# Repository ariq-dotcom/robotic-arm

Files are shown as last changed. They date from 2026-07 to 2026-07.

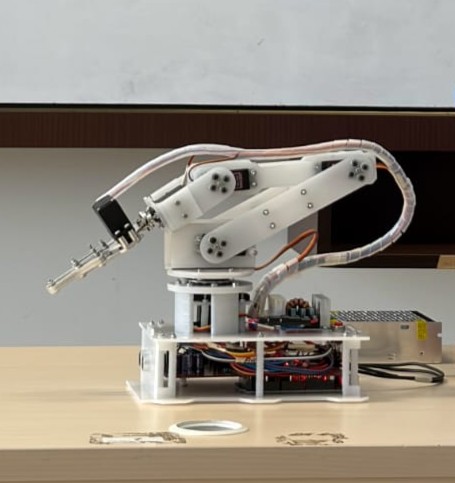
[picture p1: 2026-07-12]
Dokumentasi/4.jpeg

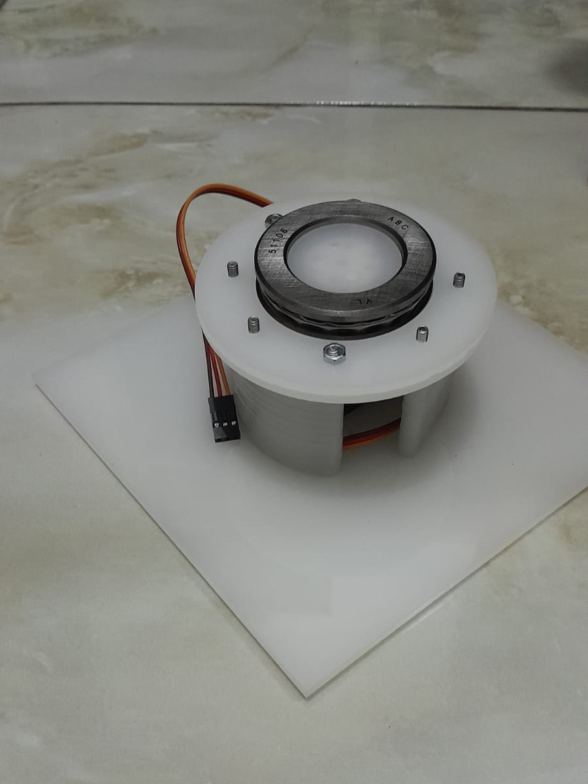
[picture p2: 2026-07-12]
Dokumentasi/1.jpeg

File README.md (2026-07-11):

Repository ini berisi file-file pengembangan robot arm 5 DOF berbasis Arduino Mega, meliputi desain elektrikal (PCB), program kendali

Pada folder ARM KENDALI, setiap angka pada nama file .ino menunjukkan urutan perkembangan dan pembaruan program sejak tahap awal pengembangan ketika isi program masih berupa struktur dasar dan belum sepenuhnya siap digunakan. File dengan angka terbesar merupakan program versi terbaru.

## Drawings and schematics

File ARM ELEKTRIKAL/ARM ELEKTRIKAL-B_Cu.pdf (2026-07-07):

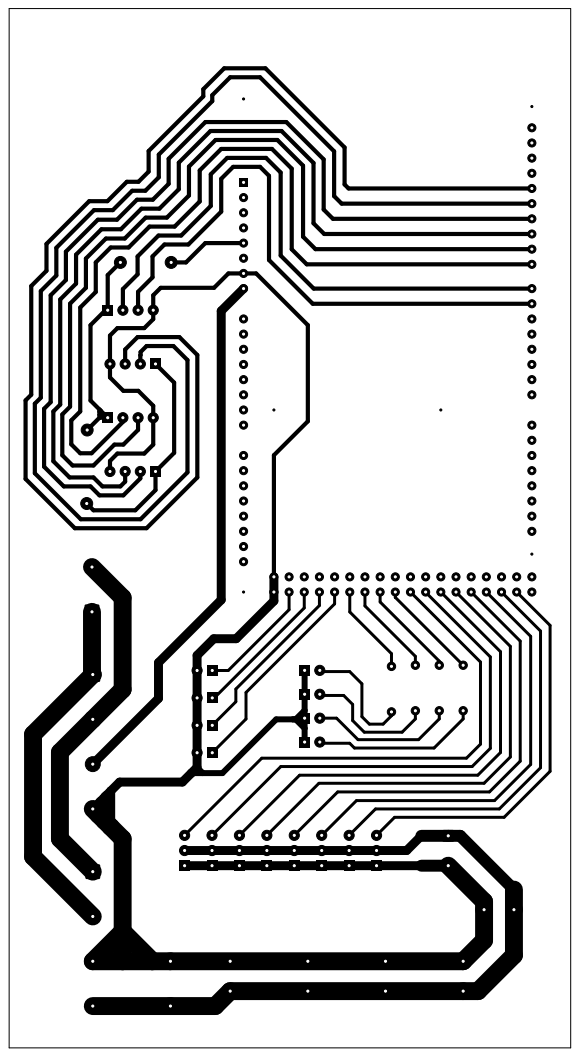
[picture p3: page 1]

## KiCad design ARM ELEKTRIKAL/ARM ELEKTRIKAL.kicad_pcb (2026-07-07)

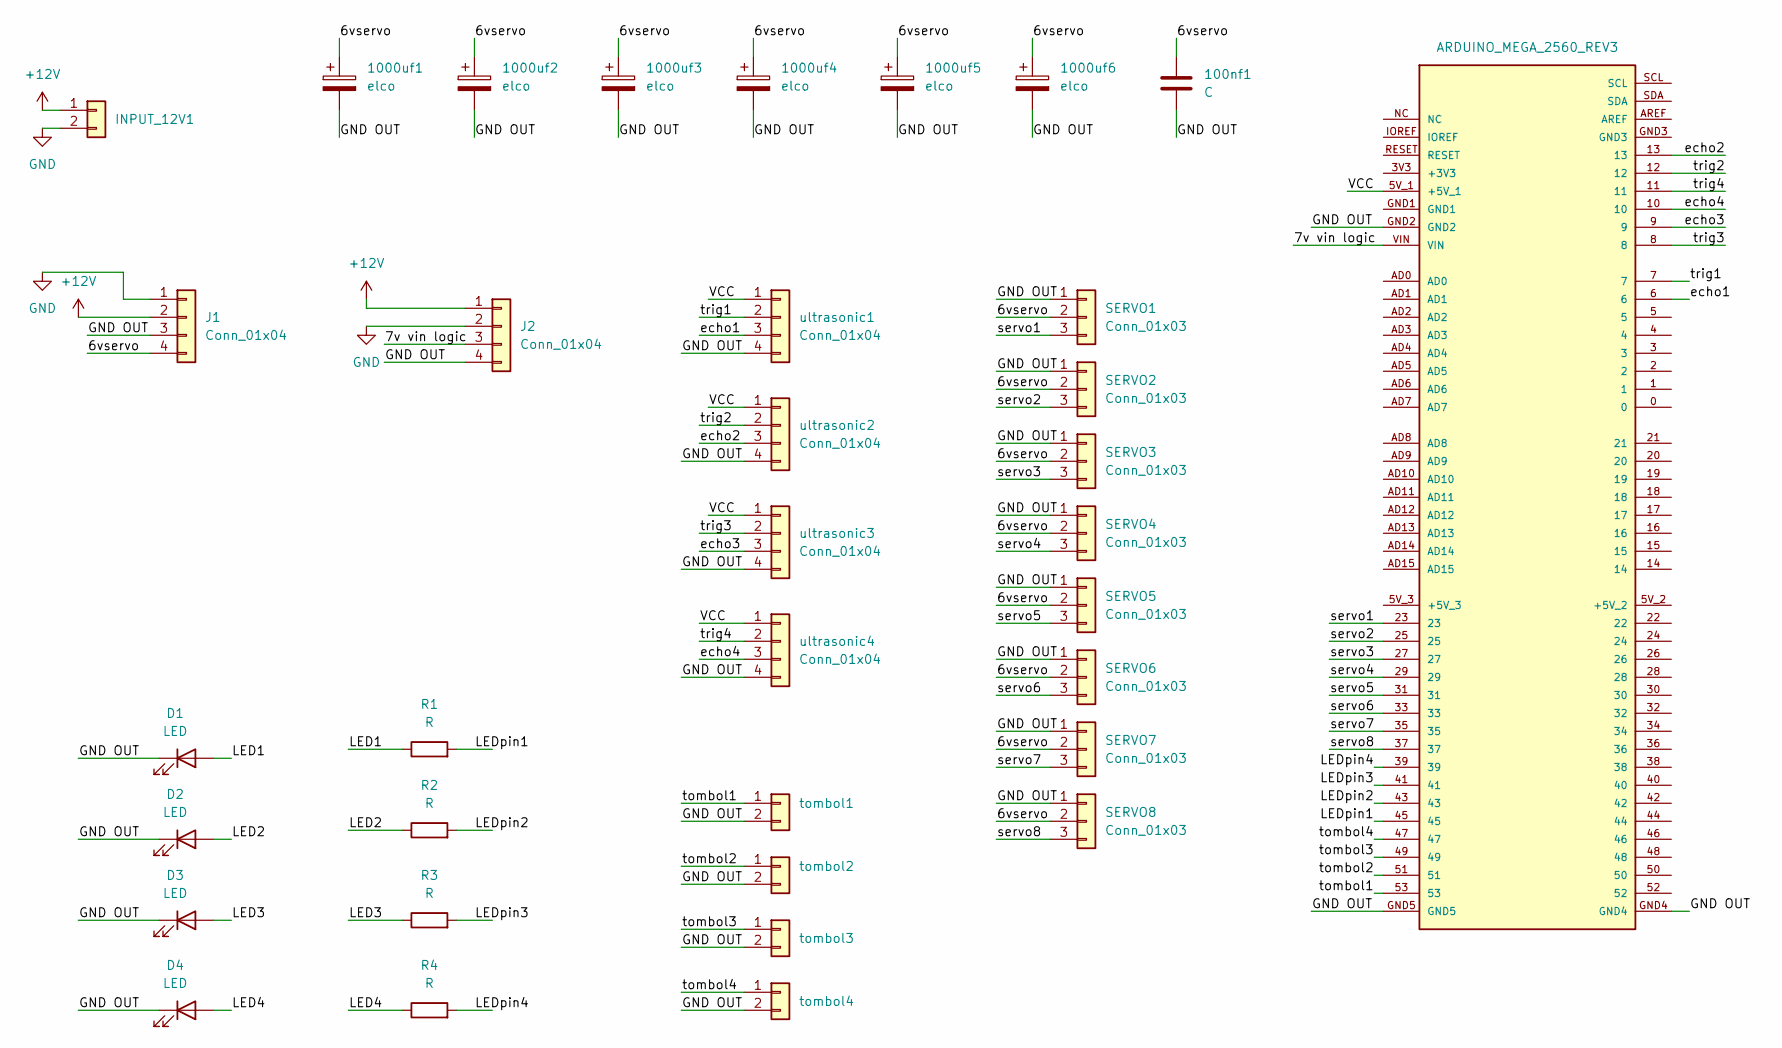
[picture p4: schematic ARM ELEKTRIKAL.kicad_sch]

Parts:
100nf1: C; C_Rect_L9.0mm_W2.7mm_P7.50mm_MKT
1000uf1, 1000uf2, 1000uf3, 1000uf4, 1000uf5, 1000uf6: elco; CP_Radial_D10.0mm_P5.00mm
A1: ARDUINO_MEGA_2560_REV3; ARDUINO_ARDUINO_MEGA_2560_REV3; PARTREV 3
D1, D2, D3, D4: LED; PinHeader_1x02_P2.54mm_Vertical
INPUT_12V1: Conn_01x02; TerminalBlock_MetzConnect_Type171_RT13702HBWC_1x02_P7.50mm_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
J1, J2: Conn_01x04; TerminalBlock_MetzConnect_Type171_RT13704HBWC_1x04_P7.50mm_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
R1, R2, R3, R4: R; R_Axial_DIN0204_L3.6mm_D1.6mm_P7.62mm_Horizontal
SERVO1, SERVO2, SERVO3, SERVO4, SERVO5, SERVO6, SERVO7, SERVO8: Conn_01x03; PinHeader_1x03_P2.54mm_Vertical
tombol1, tombol2, tombol3, tombol4: Conn_01x02; PinHeader_1x02_P2.54mm_Vertical
ultrasonic1, ultrasonic2, ultrasonic3, ultrasonic4: Conn_01x04; PinHeader_1x04_P2.54mm_Vertical

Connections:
+12V: INPUT_12V1.1, J1.2, J2.1
/6vservo: 100nf1.1, 1000uf1.1, 1000uf2.1, 1000uf3.1, 1000uf4.1, 1000uf5.1, 1000uf6.1, J1.4, SERVO1.2, SERVO2.2, SERVO3.2, SERVO4.2, SERVO5.2, SERVO6.2, SERVO7.2, SERVO8.2
/7v vin logic: A1.VIN, J2.3
/GND OUT: 100nf1.2, 1000uf1.2, 1000uf2.2, 1000uf3.2, 1000uf4.2, 1000uf5.2, 1000uf6.2, A1.GND2, A1.GND4, A1.GND5, D1.1 (K), D2.1 (K), D3.1 (K), D4.1 (K), J1.3, J2.4, SERVO1.1, SERVO2.1, SERVO3.1, SERVO4.1, SERVO5.1, SERVO6.1, SERVO7.1, SERVO8.1, tombol1.2, tombol2.2, tombol3.2, tombol4.2, ultrasonic1.4, ultrasonic2.4, ultrasonic3.4, ultrasonic4.4
/LED1: D1.2 (A), R1.1
/LED2: D2.2 (A), R2.1
/LED3: D3.2 (A), R3.1
/LED4: D4.2 (A), R4.1
/LEDpin1: A1.45, R1.2
/LEDpin2: A1.43, R2.2
/LEDpin3: A1.41, R3.2
/LEDpin4: A1.39, R4.2
/VCC: A1.5V_1 (+5V_1), ultrasonic1.1, ultrasonic2.1, ultrasonic3.1, ultrasonic4.1
/echo1: A1.6, ultrasonic1.3
/echo2: A1.13, ultrasonic2.3
/echo3: A1.9, ultrasonic3.3
/echo4: A1.10, ultrasonic4.3
/servo1: A1.23, SERVO1.3
/servo2: A1.25, SERVO2.3
/servo3: A1.27, SERVO3.3
/servo4: A1.29, SERVO4.3
/servo5: A1.31, SERVO5.3
/servo6: A1.33, SERVO6.3
/servo7: A1.35, SERVO7.3
/servo8: A1.37, SERVO8.3
/tombol1: A1.53, tombol1.1
/tombol2: A1.51, tombol2.1
/tombol3: A1.49, tombol3.1
/tombol4: A1.47, tombol4.1
/trig1: A1.7, ultrasonic1.2
/trig2: A1.12, ultrasonic2.2
/trig3: A1.8, ultrasonic3.2
/trig4: A1.11, ultrasonic4.2
GND: INPUT_12V1.2, J1.1, J2.2

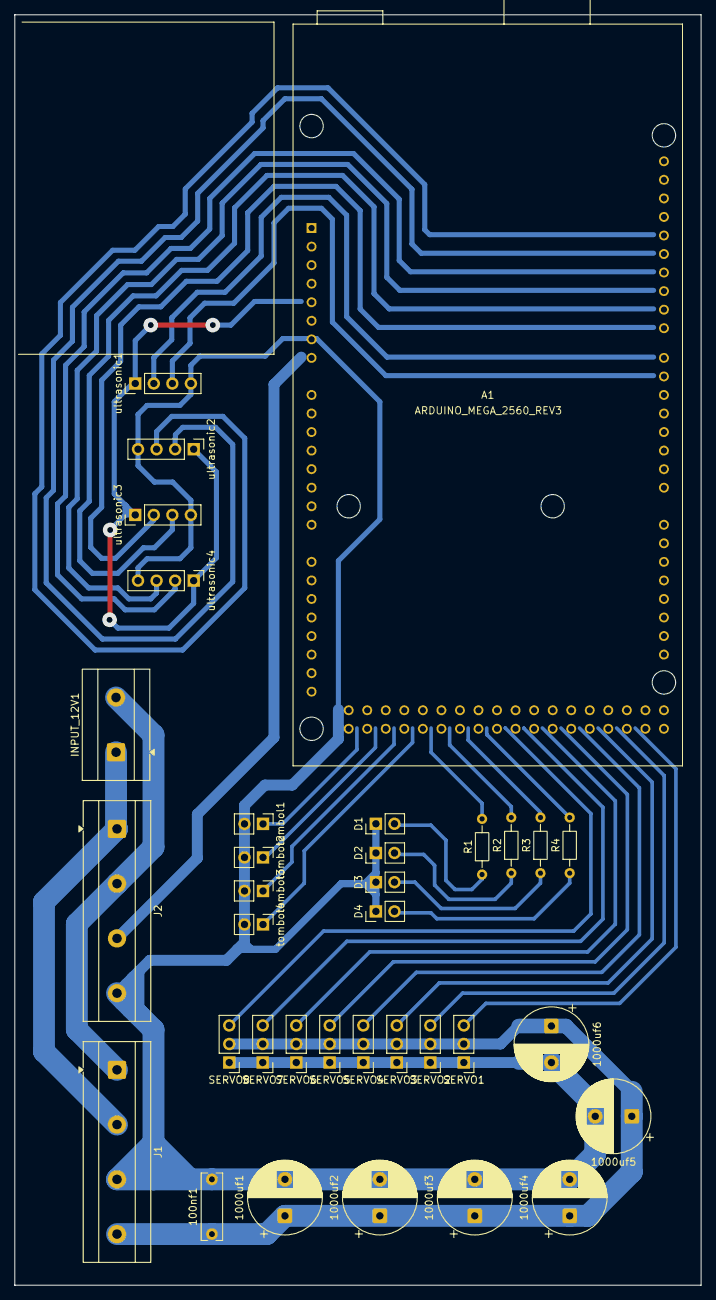
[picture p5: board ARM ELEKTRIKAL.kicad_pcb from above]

Board: 2 copper layers, 94.0 x 174.0 mm, 35 parts (0 on the bottom side), 34 nets.

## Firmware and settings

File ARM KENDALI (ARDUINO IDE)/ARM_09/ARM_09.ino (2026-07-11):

//KELOMPOK 2
#include <Arduino.h>
#include <Servo.h>

#define pinHOME 53 // posisi awal
#define pinKERJA 51 // mode kerja
#define pinDEMO 49 // mode demonstrasi (beberapa gerakan kemampuan robot)

#define ledHOME 4
#define ledKERJA 3
#define ledDEMO 2

#define TRIG_PIN 12
#define ECHO_PIN 13

enum Mode {
  HOME,
  KERJA,
  DEMO
};

Mode modeSekarang = HOME;
Mode modeDiminta = HOME;

bool tugasSelesai = true;

//AAAAAAAAAAAAASSSSSSSSSSSSSSSSSSSSSSNNNNNNNNNNNNNNGGGGGGGGGGGGGWWWWWWWWWWWWWWWWW
//AAAAAAAAAAAAASSSSSSSSSSSSSSSSSSSSSSNNNNNNNNNNNNNNGGGGGGGGGGGGGWWWWWWWWWWWWWWWWW
//AAAAAAAAAAAAASSSSSSSSSSSSSSSSSSSSSSNNNNNNNNNNNNNNGGGGGGGGGGGGGWWWWWWWWWWWWWWWWW

//nama servo
Servo base;
Servo shoulder;
Servo elbow;
Servo wristP;
Servo wristR;
Servo gripper;

#include <math.h>
//dimensi robot
const float L1 = 7.9;
const float L2 = 15.0;
const float L3 = 13.0;
const float L4 = 7.3;
const float L5 = 11;

//untuk nilai sekarang juga penyimpanan nilai saat berjalan
float sekarang_s0 = 90;
float sekarang_s1 = 20;
float sekarang_s2 = 20;
float sekarang_s3 = 117;
float sekarang_s4 = 90;

//nilai sudut untuk ke posisi home
const float HOME_s0 = 90;
const float HOME_s1 = 20;
const float HOME_s2 = 20;
const float HOME_s3 = 117;
const float HOME_s4 = 90;

// ===== PROTOTIPE FUNGSI =====
bool ik_task(float x, float y, float z_target, float phi_deg,
                      float *t0_deg, float *t1_deg, float *t2_deg, 
                      float *t3_deg, float *t4_deg);

float keServo(float sudut);

void mapkeServo(float t0, float t1, float t2, float t3, float t4,
                float *s0, float *s1, float *s2, float *s3, float *s4);

void gerakKe(float x, float y, float z, float phi, int stepDelay);

void gerakServo(float s0, float s1, float s2,
                float s3, float s4, int stepDelay);

void bacaTombol();

void updateLED();

void gerakHome();

float bacaJarak();

bool tunggu(unsigned long waktu);

//WWWWWWWWWWWWWWWWWWWWWWWWWWWWWWWWWWWWWWWWWWWWWWWWWWWWWWWWWWWWWWWW
//WWWWWWWWWWWWWWWWWWWWWWWWWWWWWWWWWWWWWWWWWWWWWWWWWWWWWWWWWWWWWWWW

void setup() {
  Serial.begin(115200);

  pinMode(pinHOME, INPUT_PULLUP);
  pinMode(pinKERJA, INPUT_PULLUP);
  pinMode(pinDEMO, INPUT_PULLUP);

  pinMode(TRIG_PIN, OUTPUT);
  pinMode(ECHO_PIN, INPUT);

  pinMode(ledHOME, OUTPUT);
  pinMode(ledKERJA, OUTPUT);
  pinMode(ledDEMO, OUTPUT);

  base.attach(23);
  shoulder.attach(31);
  elbow.attach(29);
  wristP.attach(35);
  wristR.attach(27);
  gripper.attach(25);

  base.write((int)sekarang_s0);
  shoulder.write((int)sekarang_s1);
  elbow.write((int)sekarang_s2);
  wristP.write((int)sekarang_s3);
  wristR.write((int)sekarang_s4);

  // ===== CETAK KE SERIAL (untuk monitor) =====
    Serial.print("Base: "); Serial.print((int)sekarang_s0);
    Serial.print(" | Shoulder: "); Serial.print((int)sekarang_s1);
    Serial.print(" | Elbow: "); Serial.print((int)sekarang_s2);
    Serial.print(" | WristP: "); Serial.print((int)sekarang_s3);
    Serial.print(" | WristR: "); Serial.println((int)sekarang_s4);

  delay(5000);
  updateLED();
}
//WWWWWWWWWWWWWWWWWWWWWWWWWWWWWWWWWWWWWWWWWWWWWWWWWWWWWWWWWWWWWWWW
//WWWWWWWWWWWWWWWWWWWWWWWWWWWWWWWWWWWWWWWWWWWWWWWWWWWWWWWWWWWWWWWW

//AAAAAAAAAAAAAAAAAAAAAAAAAAAAAAAAAAAAAAAAAAAAAAAAAAAAAAAAAAAAAAAA
//AAAAAAAAAAAAAAAAAAAAAAAAAAAAAAAAAAAAAAAAAAAAAAAAAAAAAAAAAAAAAAAA

void loop() {

  bacaTombol();

  // Menjalankan mode yang aktif
  switch (modeSekarang) {

//############################
//========== HOME ===========
    case HOME: {
      // Program home
      if (sekarang_s0 != HOME_s0 ||
      sekarang_s1 != HOME_s1 ||
      sekarang_s2 != HOME_s2 ||
      sekarang_s3 != HOME_s3 ||
      sekarang_s4 != HOME_s4) {
      tugasSelesai = false;
      if (!tunggu(100))
    break;
      gripper.write(95);
      gerakHome();
      tugasSelesai = true;
      }
      break;
    }
//============================
//############################
//############################
//========== KERJA ===========
    case KERJA: {
      // Program kerja
      tugasSelesai = false;

      float jarak = bacaJarak();

      if (!tunggu(100))
    break;
      
      // x,y,z,phi,delayStep
      gerakKe(-0.7, 10, 0, -90, 7);
      Serial.print("Jarak: ");
      Serial.print(jarak);
      Serial.println(" cm");
      
      if (jarak > 0 && jarak < 13) {
        Serial.println("Objek Terdeteksi");
        gripper.write(25);

        jarak = bacaJarak();
        Serial.println(jarak);
        if (!tunggu(1000))
      break;

        jarak = bacaJarak();
        Serial.println(jarak);
        if (!tunggu(1000))
      break;

        jarak = bacaJarak();
        Serial.println(jarak);
        if (!tunggu(1000))
      break;

        //+8 cm adalah jarak awal persis depan sensor, 
        //dihitung dari titik pusat invers kinematik ke sensor
        //lalu + setelahnya untuk offset seberapa panjang lebar objek yang diambil
        //menyesuaikan agar posisi capitan pas
        
        gerakKe(-0.7, 8+jarak +1, 0, -90, 7);
        if (!tunggu(1000))
      break;
        gerakKe(-0.7, 8+jarak +1, -5, -90, 7);
        if (!tunggu(1000))
      break;
        gripper.write(95);
        if (!tunggu(1000))
      break;
        gerakKe(-0.7, 8+jarak +1, 0, -90, 7);
        if (!tunggu(1000))
      break;

      // ==== lanjutan ====
        gerakKe(-13, 0, 0, -90, 7);
        if (!tunggu(1000))
      break;
        gerakKe(-13, 0, -5, -90, 7);
        if (!tunggu(1000))
      break;
        gripper.write(25);
        if (!tunggu(2000))
      break;
        gerakKe(-13, 7, -5, -90, 10);
        if (!tunggu(500))
      break;

      }

      tugasSelesai = true;
      break;
    }
//============================
//############################
//############################
//========== DEMO ===========
    case DEMO: {
      // Program demo
      tugasSelesai = false;

      // x,y,z,phi,delayStep
      gerakKe(0, 15, 0, -90, 7);
      if (!tunggu(2000))
    break;
      gripper.write(25);
      if (!tunggu(1000))
    break;
      gerakKe(0, 15, 0, -90, 7);
      if (!tunggu(1000))
    break;
      gerakKe(0, 15, -5, -90, 7);
      gripper.write(95);
      if (!tunggu(1000))
    break;

      gerakKe(0, 15, 0, -90, 7);
      if (!tunggu(1000))
    break;
      gerakKe(15, 0, 0, -90, 7);
      if (!tunggu(1000))
    break;
      gerakKe(15, 0, -5, -90, 7);
      if (!tunggu(1000))
    break;
      gripper.write(25);
      if (!tunggu(1000))
    break;
      gripper.write(95);
      if (!tunggu(1000))
    break;
      gerakKe(15, 0, 0, -90, 7);
      if (!tunggu(1000))
    break;

      gerakKe(-15, 0, 0, -90, 7);
      if (!tunggu(1000))
    break;
      gerakKe(-15, 0, -5, -90, 7);
      if (!tunggu(1000))
    break;
      gripper.write(25);
      if (!tunggu(1000))
    break;
      gripper.write(95);
      if (!tunggu(1000))
    break;
      gerakKe(-15, 0, 0, -90, 7);
      if (!tunggu(1000))
    break;

      tugasSelesai = true;
      break;
    }
  }
//============================
//############################
  
    if (tugasSelesai && modeDiminta != modeSekarang) {
      modeSekarang = modeDiminta;
      updateLED();
      Serial.print("Pindah ke mode : ");

      switch (modeSekarang) {

        case HOME:
          Serial.println("HOME");
          break;

        case KERJA:
          Serial.println("KERJA");
          break;

        case DEMO:
          Serial.println("DEMO");
          break;
      }
    }
}
//AAAAAAAAAAAAAAAAAAAAAAAAAAAAAAAAAAAAAAAAAAAAAAAAAAAAAAAAAAAAAAAA
//AAAAAAAAAAAAAAAAAAAAAAAAAAAAAAAAAAAAAAAAAAAAAAAAAAAAAAAAAAAAAAAA

//################################################################
// FUNGSI IK, FUNGSI IK, FUNGSI IK
//################################################################
// ==== FUNGSI IK ====
bool ik_task(float x, float y, float z_target, float phi_deg,
                      float *t0_deg, float *t1_deg, float *t2_deg, 
                      float *t3_deg, float *t4_deg) {

  // ===== Base rotation =====
  float theta0 = atan2(y, x);
  float theta0_deg = theta0 * 180.0 / PI;
  
  // ===== Wrist rotation =====
  // menjaga agar gripper menyesuaikan arah base
  float theta4_deg = theta0_deg;
  
  // ===== Transformasi ke plane =====
  float x_plane_tcp = x * cos(theta0) + y * sin(theta0);
  float y_plane_tcp = z_target - L1;

  // ===== Tool offset =====
  float L_tool = L4 + L5;
  float phi = phi_deg * PI / 180.0;  // konversi ke radian
  
  float x_plane = x_plane_tcp - L_tool * cos(phi);
  float y_plane = y_plane_tcp - L_tool * sin(phi);
  
  // ===== Jarak ke shoulder =====
  float r = sqrt(x_plane * x_plane + y_plane * y_plane);

  // ===== Cek workspace =====
  if (r > (L2 + L3) || r < fabs(L2 - L3))
  {
    Serial.print("Target di luar workspace : ");
    Serial.print(x);
    Serial.print(", ");
    Serial.print(y);
    Serial.print(", ");
    Serial.println(z_target);  

    return false;
  }
  
  // ===== Elbow-up solution =====
  float cos_theta2 = (x_plane*x_plane + y_plane*y_plane - L2*L2 - L3*L3) / (2.0 * L2 * L3);
  cos_theta2 = constrain(cos_theta2, -1.0, 1.0);
  float theta2 = -acos(cos_theta2);
  
  float k1 = L2 + L3 * cos(theta2);
  float k2 = L3 * sin(theta2);

  float theta1 = atan2(y_plane, x_plane) - atan2(k2, k1);
  
  // ===== Wrist pitch =====
  float theta3 = phi - (theta1 + theta2);
  
  // ===== Konversi ke derajat =====
  float theta1_deg = theta1 * 180.0 / PI;
  float theta2_deg = theta2 * 180.0 / PI;
  float theta3_deg = theta3 * 180.0 / PI;

  // ===== KEMBALIKAN HASIL via pointer =====
  *t0_deg = theta0_deg;
  *t1_deg = theta1_deg;
  *t2_deg = theta2_deg;
  *t3_deg = theta3_deg;
  *t4_deg = theta4_deg;

  return true;
}
//################################################################
//################################################################

//MMMMMMMMMMMMMMMMMMMMMMMMMMMMMMMMMMMMMMMMMMMMMMMMMMMMMMMMMMMMMMMM
// FUNGSI MAPPING DAN CLAMP
//MMMMMMMMMMMMMMMMMMMMMMMMMMMMMMMMMMMMMMMMMMMMMMMMMMMMMMMMMMMMMMMM

//==== CLAMP ====
float keServo(float sudut) {
  if (sudut < 0) return 0;
  if (sudut > 180) return 180;
  return sudut;
}

//==== MAPPING ====
void mapkeServo(float t0, float t1, float t2, float t3, float t4,
                float *s0, float *s1, float *s2, float *s3, float *s4) {
  // =======================================
  // KOREKSI DARI GAMBAR (MATEMATIKA) KE MEKANIK
  // =======================================
  *s0 = t0;
  *s1 = 180 - t1;
  *s2 = t2 + 180;
  *s3 = 180 - (t3 + 90);
  *s4 = t4;
  // ============
  // CLAMP 0–180
  // ============
  *s0 = keServo(*s0);
  *s1 = keServo(*s1);
  *s2 = keServo(*s2);
  *s3 = keServo(*s3);
  *s4 = keServo(*s4);
}

//MMMMMMMMMMMMMMMMMMMMMMMMMMMMMMMMMMMMMMMMMMMMMMMMMMMMMMMMMMMMMMMM
//MMMMMMMMMMMMMMMMMMMMMMMMMMMMMMMMMMMMMMMMMMMMMMMMMMMMMMMMMMMMMMMM

//################################################################
//FUNGSI GERAKAN HALUS
//################################################################

void gerakKe(float x, float y, float z, float phi, int stepDelay) {

  // ===== TARGET IK =====
  float t0, t1, t2, t3, t4;

  // ===== TARGET SERVO =====
  float s0, s1, s2, s3, s4;

  // ===== IK =====
  if (!ik_task(x, y, z, phi,
          &t0, &t1, &t2, &t3, &t4))
  {
    return;
  }

  // ===== MAPPING =====
  mapkeServo(t0, t1, t2, t3, t4,
             &s0, &s1, &s2, &s3, &s4);

  gerakServo(s0, s1, s2, s3, s4, stepDelay);
}
//################################################################
//################################################################

//MMMMMMMMMMMMMMMMMMMMMMMMMMMMMMMMMMMMMMMMMMMMMMMMMMMMMMMMMMMMMMMM
// FUNGSI BACA TOMBOL
//MMMMMMMMMMMMMMMMMMMMMMMMMMMMMMMMMMMMMMMMMMMMMMMMMMMMMMMMMMMMMMMM

void bacaTombol() {

  static unsigned long lastDebounce = 0;

  if (millis() - lastDebounce < 200)
    return;

  if (digitalRead(pinHOME) == LOW &&
      modeSekarang != HOME) {

    modeDiminta = HOME;
    Serial.println("Mode HOME diminta");
    lastDebounce = millis();
  }

  else if (digitalRead(pinKERJA) == LOW &&
           modeSekarang != KERJA) {

    modeDiminta = KERJA;
    Serial.println("Mode KERJA diminta");
    lastDebounce = millis();
  }

  else if (digitalRead(pinDEMO) == LOW &&
           modeSekarang != DEMO) {

    modeDiminta = DEMO;
    Serial.println("Mode DEMO diminta");
    lastDebounce = millis();
  }
}

//MMMMMMMMMMMMMMMMMMMMMMMMMMMMMMMMMMMMMMMMMMMMMMMMMMMMMMMMMMMMMMMM
//MMMMMMMMMMMMMMMMMMMMMMMMMMMMMMMMMMMMMMMMMMMMMMMMMMMMMMMMMMMMMMMM

//################################################################
// FUNGSI GERAK, LINEAR INTERPOLATION
//################################################################
void gerakServo(float s0, float s1, float s2,
                float s3, float s4, int stepDelay)
{
  float start_s0 = sekarang_s0;
  float start_s1 = sekarang_s1;
  float start_s2 = sekarang_s2;
  float start_s3 = sekarang_s3;
  float start_s4 = sekarang_s4;

  float d0 = fabs(s0 - start_s0);
  float d1 = fabs(s1 - start_s1);
  float d2 = fabs(s2 - start_s2);
  float d3 = fabs(s3 - start_s3);
  float d4 = fabs(s4 - start_s4);

  float maxDelta = d0;

  if (d1 > maxDelta) maxDelta = d1;
  if (d2 > maxDelta) maxDelta = d2;
  if (d3 > maxDelta) maxDelta = d3;
  if (d4 > maxDelta) maxDelta = d4;

  int steps = (int)maxDelta;

  if (steps < 1)
    steps = 1;

  for (int i = 1; i <= steps; i++) {

    float p = (float) i / steps;

    sekarang_s0 = start_s0 + (s0 - start_s0) * p;
    sekarang_s1 = start_s1 + (s1 - start_s1) * p;
    sekarang_s2 = start_s2 + (s2 - start_s2) * p;
    sekarang_s3 = start_s3 + (s3 - start_s3) * p;
    sekarang_s4 = start_s4 + (s4 - start_s4) * p;
    
    bacaTombol();

    if (modeDiminta != modeSekarang)
        return;
      
    base.write((int)sekarang_s0);
    shoulder.write((int)sekarang_s1);
    elbow.write((int)sekarang_s2);
    wristP.write((int)sekarang_s3);
    wristR.write((int)sekarang_s4);

    Serial.print("Base: "); Serial.print((int)sekarang_s0);
    Serial.print(" | Shoulder: "); Serial.print((int)sekarang_s1);
    Serial.print(" | Elbow: "); Serial.print((int)sekarang_s2);
    Serial.print(" | WristP: "); Serial.print((int)sekarang_s3);
    Serial.print(" | WristR: "); Serial.println((int)sekarang_s4);

    delay(stepDelay);
  }

  sekarang_s0 = s0;
  sekarang_s1 = s1;
  sekarang_s2 = s2;
  sekarang_s3 = s3;
  sekarang_s4 = s4;
}

//################################################################
//################################################################

//MMMMMMMMMMMMMMMMMMMMMMMMMMMMMMMMMMMMMMMMMMMMMMMMMMMMMMMMMMMMMMMM
// FUNGSI UPDATE LED
//MMMMMMMMMMMMMMMMMMMMMMMMMMMMMMMMMMMMMMMMMMMMMMMMMMMMMMMMMMMMMMMM
void updateLED() {

  digitalWrite(ledHOME, modeSekarang == HOME);
  digitalWrite(ledKERJA, modeSekarang == KERJA);
  digitalWrite(ledDEMO, modeSekarang == DEMO);
}
//MMMMMMMMMMMMMMMMMMMMMMMMMMMMMMMMMMMMMMMMMMMMMMMMMMMMMMMMMMMMMMMM
//MMMMMMMMMMMMMMMMMMMMMMMMMMMMMMMMMMMMMMMMMMMMMMMMMMMMMMMMMMMMMMMM

//################################################################
// FUNGSI KEMBALI KE POSISI HOME
//################################################################
void gerakHome()
{
    gerakServo(
        HOME_s0,
        HOME_s1,
        HOME_s2,
        HOME_s3,
        HOME_s4,
        7
    );
}
//################################################################
//################################################################

//AAAAAAAAAAAAAAAAAAAAAAAAAAAAAAAAAAAAAAAAAAAAAAAAAAAAAAAAAAAAAAAA
// FUNGSI BACA JARAK
//AAAAAAAAAAAAAAAAAAAAAAAAAAAAAAAAAAAAAAAAAAAAAAAAAAAAAAAAAAAAAAAA
float bacaJarak() {
  digitalWrite(TRIG_PIN, LOW);
  delayMicroseconds(2);

  digitalWrite(TRIG_PIN, HIGH);
  delayMicroseconds(10);

  digitalWrite(TRIG_PIN, LOW);

  long durasi = pulseIn(ECHO_PIN, HIGH, 30000);

  if (durasi == 0) {
    return -1;
  }

  float jarak = durasi * 0.034 / 2.0;

  return jarak;
}
//AAAAAAAAAAAAAAAAAAAAAAAAAAAAAAAAAAAAAAAAAAAAAAAAAAAAAAAAAAAAAAAA
//AAAAAAAAAAAAAAAAAAAAAAAAAAAAAAAAAAAAAAAAAAAAAAAAAAAAAAAAAAAAAAAA

//################################################################
// FUNGSI TUNGGU, PENGGANTI DELAY AGAR RESPONSIF
//################################################################

bool tunggu(unsigned long waktu)
{
    unsigned long mulai = millis();

    while (millis() - mulai < waktu)
    {
        bacaTombol();

        if (modeDiminta != modeSekarang)
        {
            tugasSelesai = true;
            return false;
        }
    }

    return true;
}

//################################################################
//################################################################




//AAAAAAAAAAAAASSSSSSSSSSSSSSSSSSSSSSNNNNNNNNNNNNNNGGGGGGGGGGGGGWWWWWWWWWWWWWWWWW
//AAAAAAAAAAAAASSSSSSSSSSSSSSSSSSSSSSNNNNNNNNNNNNNNGGGGGGGGGGGGGWWWWWWWWWWWWWWWWW
//AAAAAAAAAAAAASSSSSSSSSSSSSSSSSSSSSSNNNNNNNNNNNNNNGGGGGGGGGGGGGWWWWWWWWWWWWWWWWW

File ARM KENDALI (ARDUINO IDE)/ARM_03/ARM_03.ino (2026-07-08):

#include <Arduino.h>
#include <Servo.h>

#define pinhome 13 // posisi awal
#define pinwork 12 // mode kerja
#define pindemo 8 // mode demonstrasi (beberapa gerakan kemampuan robot)
//sensor
#define sensor 11 //sensor untuk mode kerja (belum tau sensor apa)
//nama servo
Servo base;
Servo shoulder;
Servo elbow;
Servo wristP;
Servo wristR;
Servo gripper;

#include <math.h>
//dimensi robot
const float L1 = 8.5;
const float L2 = 15.0;
const float L3 = 13.0;
const float L4 = 6.5;
const float L5 = 12.0;

int sekarang_s0 = 90;
int sekarang_s1 = 20;
int sekarang_s2 = 20;
int sekarang_s3 = 90;
int sekarang_s4 = 90;

// ===== PROTOTIPE FUNGSI =====

void ik_task(float x, float y, float z_target, float phi_deg,
                      float *t0_deg, float *t1_deg, float *t2_deg, 
                      float *t3_deg, float *t4_deg);

int keServo(int sudut);

void mapkeServo(int t0, int t1, int t2, int t3, int t4,
                int *s0, int *s1, int *s2, int *s3, int *s4);

void smoothMove(Servo &servo,
                int &currentPos,
                int targetPos,
                int delaySpeed);

void setup() {
  pinMode(pinhome, INPUT_PULLUP);
  pinMode(pinwork, INPUT_PULLUP);
  pinMode(pindemo, INPUT_PULLUP);
  
  base.attach(5);
  shoulder.attach(4);
  elbow.attach(6);
  wristP.attach(2);
  wristR.attach(7);
  gripper.attach(3);

  Serial.begin(115200);
  
  base.write(sekarang_s0);
  shoulder.write(sekarang_s1);
  elbow.write(sekarang_s2);
  wristP.write(sekarang_s3);
  wristR.write(sekarang_s4);

  delay(10000);
}

//AAAAAAAAAAAAASSSSSSSSSSSSSSSSSSSSSSNNNNNNNNNNNNNNGGGGGGGGGGGGGWWWWWWWWWWWWWWWWW
//AAAAAAAAAAAAASSSSSSSSSSSSSSSSSSSSSSNNNNNNNNNNNNNNGGGGGGGGGGGGGWWWWWWWWWWWWWWWWW
//AAAAAAAAAAAAASSSSSSSSSSSSSSSSSSSSSSNNNNNNNNNNNNNNGGGGGGGGGGGGGWWWWWWWWWWWWWWWWW





//AAAAAAAAAAAAAAAAAAAAAAAAAAAAAAAAAAAAAAAAAAAAAAAAAAAAAAAAAAAAAAAA
//AAAAAAAAAAAAAAAAAAAAAAAAAAAAAAAAAAAAAAAAAAAAAAAAAAAAAAAAAAAAAAAA

void loop() {

  // ===== VARIABEL PENAMPUNG IK =====
  float x, y, z, phi;

  float t0, t1, t2, t3, t4;

  // ===== VARIABEL SERVO =====
  int s0, s1, s2, s3, s4;
  
  //satu
  x = -10.0;
  y = 15.0;
  z = 0.0;
  phi = -90;
  ik_task(x, y, z, phi, &t0, &t1, &t2, &t3, &t4);
  mapkeServo((int)t0, (int)t1, (int)t2, (int)t3, (int)t4,
             &s0, &s1, &s2, &s3, &s4);
  // ===== CETAK KE SERIAL (untuk monitor) =====
  Serial.print("Base: "); Serial.print((int)s0);
  Serial.print(" | Shoulder: "); Serial.print((int)s1);
  Serial.print(" | Elbow: "); Serial.print((int)s2);
  Serial.print(" | WristP: "); Serial.print((int)s3);
  Serial.print(" | WristR: "); Serial.println((int)s4);
  smoothMove(base, sekarang_s0, s0, 20);
  delay(1000);
  smoothMove(shoulder, sekarang_s1, s1, 20);
  smoothMove(elbow, sekarang_s2, s2, 20);
  smoothMove(wristP, sekarang_s3, s3, 20);
  smoothMove(wristR, sekarang_s4, s4, 20);
  delay(10000);
  gripper.write(25);
  delay(500);
  gripper.write(90);
  

  //tiga
  x = 10.0;
  y = 15.0;
  z = 0.0;
  phi = -90;
  ik_task(x, y, z, phi, &t0, &t1, &t2, &t3, &t4);
  mapkeServo((int)t0, (int)t1, (int)t2, (int)t3, (int)t4,
             &s0, &s1, &s2, &s3, &s4);
  // ===== CETAK KE SERIAL (untuk monitor) =====
  Serial.print("Base: "); Serial.print((int)s0);
  Serial.print(" | Shoulder: "); Serial.print((int)s1);
  Serial.print(" | Elbow: "); Serial.print((int)s2);
  Serial.print(" | WristP: "); Serial.print((int)s3);
  Serial.print(" | WristR: "); Serial.println((int)s4);
  smoothMove(base, sekarang_s0, s0, 20);
  delay(1000);
  smoothMove(shoulder, sekarang_s1, s1, 20);
  smoothMove(elbow, sekarang_s2, s2, 20);
  smoothMove(wristP, sekarang_s3, s3, 20);
  smoothMove(wristR, sekarang_s4, s4, 20);
  delay(10000);
  gripper.write(25);
  delay(500);
  gripper.write(90);

  
}
//AAAAAAAAAAAAAAAAAAAAAAAAAAAAAAAAAAAAAAAAAAAAAAAAAAAAAAAAAAAAAAAA
//AAAAAAAAAAAAAAAAAAAAAAAAAAAAAAAAAAAAAAAAAAAAAAAAAAAAAAAAAAAAAAAA





//################################################################
// FUNGSI IK, FUNGSI IK, FUNGSI IK
//################################################################

// ==== FUNGSI IK ====
void ik_task(float x, float y, float z_target, float phi_deg,
                      float *t0_deg, float *t1_deg, float *t2_deg, 
                      float *t3_deg, float *t4_deg) {
  
  // ===== Base rotation =====
  float theta0 = atan2(y, x);
  float theta0_deg = theta0 * 180.0 / PI;
  
  // ===== Wrist rotation =====
  // menjaga agar gripper menyesuaikan arah base
  float theta4_deg = theta0_deg;
  
  // ===== Transformasi ke plane =====
  float x_plane_tcp = x * cos(theta0) + y * sin(theta0);
  float y_plane_tcp = z_target - L1;

  // ===== Tool offset =====
  float L_tool = L4 + L5;
  float phi = phi_deg * PI / 180.0;  // konversi ke radian
  
  float x_plane = x_plane_tcp - L_tool * cos(phi);
  float y_plane = y_plane_tcp - L_tool * sin(phi);
  
  // ===== Jarak ke shoulder =====
  //float r = sqrt(x_plane * x_plane + y_plane * y_plane);
  
  // ===== Elbow-up solution =====
  float cos_theta2 = (x_plane*x_plane + y_plane*y_plane - L2*L2 - L3*L3) / (2.0 * L2 * L3);
  cos_theta2 = constrain(cos_theta2, -1.0, 1.0);
  float theta2 = -acos(cos_theta2);
  
  float k1 = L2 + L3 * cos(theta2);
  float k2 = L3 * sin(theta2);

  float theta1 = atan2(y_plane, x_plane) - atan2(k2, k1);
  
  // ===== Wrist pitch =====
  float theta3 = phi - (theta1 + theta2);
  
  // ===== Konversi ke derajat =====
  float theta1_deg = theta1 * 180.0 / PI;
  float theta2_deg = theta2 * 180.0 / PI;
  float theta3_deg = theta3 * 180.0 / PI;

  // ===== KEMBALIKAN HASIL via pointer =====
  *t0_deg = theta0_deg;
  *t1_deg = theta1_deg;
  *t2_deg = theta2_deg;
  *t3_deg = theta3_deg;
  *t4_deg = theta4_deg;
}
//################################################################
//################################################################





//MMMMMMMMMMMMMMMMMMMMMMMMMMMMMMMMMMMMMMMMMMMMMMMMMMMMMMMMMMMMMMMM
// FUNGSI MAPPING DAN CLAMP
//MMMMMMMMMMMMMMMMMMMMMMMMMMMMMMMMMMMMMMMMMMMMMMMMMMMMMMMMMMMMMMMM

//==== CLAMP ====
int keServo(int sudut) {
  if (sudut < 0) return 0;
  if (sudut > 180) return 180;
  return sudut;
}

//==== MAPPING ====
void mapkeServo(int t0, int t1, int t2, int t3, int t4,
                int *s0, int *s1, int *s2, int *s3, int *s4) {
  // =========================
  // KOREKSI MEKANIK
  // =========================
  *s0 = t0;
  *s1 = 180 - t1;
  *s2 = t2 + 180;
  *s3 = 180 - (t3 + 90);
  *s4 = t4;
  // =========================
  // CLAMP 0–180
  // =========================
  *s0 = keServo(*s0);
  *s1 = keServo(*s1);
  *s2 = keServo(*s2);
  *s3 = keServo(*s3);
  *s4 = keServo(*s4);
}
//MMMMMMMMMMMMMMMMMMMMMMMMMMMMMMMMMMMMMMMMMMMMMMMMMMMMMMMMMMMMMMMM
//MMMMMMMMMMMMMMMMMMMMMMMMMMMMMMMMMMMMMMMMMMMMMMMMMMMMMMMMMMMMMMMM





//################################################################
//FUNGSI GERAKAN HALUS
//################################################################
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

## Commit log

2026-07-08 Clarify sensor definition comment in ARM_00.ino
    Updated comment for sensor definition to clarify usage.
2026-07-08 Clarify sensor definition comment in ARM_01.ino
2026-07-08 Clarify sensor definition comment in ARM_02.ino
2026-07-08 Fix comment for sensor definition clarity
    [ARM_00.ino]
2026-07-08 Add Arduino.h include to ARM_00.ino
2026-07-08 Update comment for sensor definition clarity
2026-07-11 Fix sentence structure in README.md
    Removed a comma for better sentence flow.
